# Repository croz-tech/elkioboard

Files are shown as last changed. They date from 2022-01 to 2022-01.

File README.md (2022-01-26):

# elkioboard
I/O board for Acorn Electron (with user port cart) or BBC Micro range

Compatible with many 8-bit robot or control projects. Inputs are for switches (switches from input to +5V), Outputs drive relays.
|Bit  |Alloc |Details |
|-----|---|---|
|PB0  | Out only | DPDT relay (can be configured to reverse a motor drive)|
|PB1  | Out only | SPDT relay|
|PB2  | In/Out | Input switched to +5V  / SPDT relay (selectable by JP1)|
|PB3  | In/Out | Input switched to +5V  / SPDT relay (selectable by JP2)|
|PB4  | In/Out | Input switched to +5V  / SPDT relay (selectable by JP3)|
|PB5  | In/Out | Input switched to +5V  / SPDT relay (selectable by JP4)|
|PB6  | In only  | Input switched to +5V|
|PB7  | In only  | Input switched to +5V|

Includes a local 5V supply (since the total load with all specified relays energized may be too much for the user port itself, and generates an adjustable MOTPWR supply for motors, solenoids etc that the system is driving.  MOTPWR can be monitored with a small DVM module (3-pin header provided).  There is also a header and power/ground for CB1/CB2 from the user port (not used on this board).

## Notes
- Remember the base address for the 6522 PIA is &FE6x BBC Micro and &FCBx Electron with user port cartiridge in a Plus 1
- RV1 needs to be 5x5mm pin spacing, specified as 500R but 1K also works just fine and gives an adjustable motor supply of 2.5~9V approx.

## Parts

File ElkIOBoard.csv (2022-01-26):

Reference | Quantity | Value | Footprint | Datasheet
C1 | 1 | 10uF 16V | Capacitor_THT:CP_Radial_D5.0mm_P2.00mm | ~
C2 | 1 | 470uF, 25V | Capacitor_THT:CP_Radial_D10.0mm_P5.00mm | ~
C3 | 1 | 100uF, 25V | Capacitor_THT:CP_Radial_D6.3mm_P2.50mm | ~
C4 | 1 | 100nF | Capacitor_THT:C_Rect_L7.0mm_W2.5mm_P5.00mm | ~
F1 | 1 | Polyfuse (1.5A rec) | Capacitor_THT:C_Disc_D10.5mm_W5.0mm_P5.00mm | ~
J1 | 1 | POWER IN | TerminalBlock_Philmore:TerminalBlock_Philmore_TB132_1x02_P5.00mm_Horizontal | ~
J10 | 1 | In bit 6 | TerminalBlock_Philmore:TerminalBlock_Philmore_TB132_1x02_P5.00mm_Horizontal | ~
J11 | 1 | In bit 7 | TerminalBlock_Philmore:TerminalBlock_Philmore_TB132_1x02_P5.00mm_Horizontal | ~
J12 J13 J14 J15 J16 J17 J18 | 7 | NO.COM.NC | TerminalBlock_Philmore:TerminalBlock_Philmore_TB133_1x03_P5.00mm_Horizontal | ~
J2 | 1 | POWER OUT | TerminalBlock_Philmore:TerminalBlock_Philmore_TB132_1x02_P5.00mm_Horizontal | ~
J3 | 1 | USER PORT | ElkIOBoard:20W_IDC_TERM | ~
J4 | 1 | EXP CONN | Connector_PinHeader_2.54mm:PinHeader_1x05_P2.54mm_Vertical | ~
J5 | 1 | DVM | Connector_PinHeader_2.54mm:PinHeader_1x03_P2.54mm_Vertical | ~
J6 | 1 | In bit 2 | TerminalBlock_Philmore:TerminalBlock_Philmore_TB132_1x02_P5.00mm_Horizontal | ~
J7 | 1 | In bit 3 | TerminalBlock_Philmore:TerminalBlock_Philmore_TB132_1x02_P5.00mm_Horizontal | ~
J8 | 1 | In bit 4 | TerminalBlock_Philmore:TerminalBlock_Philmore_TB132_1x02_P5.00mm_Horizontal | ~
J9 | 1 | In bit 5 | TerminalBlock_Philmore:TerminalBlock_Philmore_TB132_1x02_P5.00mm_Horizontal | ~
JP1 JP2 JP3 JP4 | 4 | Jumper_3_Bridged12 | Connector_PinHeader_2.54mm:PinHeader_1x03_P2.54mm_Vertical | ~
K1 K2 K3 K4 K5 | 5 | SRD-05VDC-SL-C | Relay_THT:Relay_SPDT_SANYOU_SRD_Series_Form_C | http://www.sanyourelay.ca/public/products/pdf/SRD.pdf
K6 | 1 | FINDER DPDT5V | Relay_THT:Relay_DPDT_Finder_30.22 | http://gfinder.findernet.com/assets/Series/354/S30EN.pdf
LED1 | 1 | STATUS | Display:HDSP-4830 | https://docs.broadcom.com/docs/AV02-1798EN
R1 R2 R3 R4 R5 R6 | 6 | 220R | Resistor_THT:R_Axial_DIN0207_L6.3mm_D2.5mm_P10.16mm_Horizontal | ~
R7 R8 R9 R10 R11 R12 | 6 | 10K | Resistor_THT:R_Axial_DIN0207_L6.3mm_D2.5mm_P10.16mm_Horizontal | ~
R13 R14 R15 R16 R17 R18 | 6 | 2K2 | Resistor_THT:R_Axial_DIN0207_L6.3mm_D2.5mm_P10.16mm_Horizontal | ~
R19 | 1 | 130R | Resistor_THT:R_Axial_DIN0207_L6.3mm_D2.5mm_P10.16mm_Horizontal | ~
RN1 RN2 | 2 | 150R | Resistor_THT:R_Array_SIP6 | http://www.vishay.com/docs/31509/csc.pdf
RV1 | 1 | 500R | Potentiometer_THT:Potentiometer_Piher_PT-10-V05_Vertical | ~
U1 | 1 | ULN2003A | Package_DIP:DIP-16_W7.62mm_LongPads | http://www.ti.com/lit/ds/symlink/uln2003a.pdf
U2 | 1 | LM7805 | Package_TO_SOT_THT:TO-220-3_Horizontal_TabDown | http://www.fairchildsemi.com/ds/LM/LM7805.pdf
U3 | 1 | LM317T | Package_TO_SOT_THT:TO-220-3_Horizontal_TabDown | http://www.ti.com/lit/ds/symlink/lm317.pdf
U4 | 1 | 74LS240 | Package_DIP:DIP-20_W7.62mm_LongPads | http://www.ti.com/lit/gpn/sn74LS240

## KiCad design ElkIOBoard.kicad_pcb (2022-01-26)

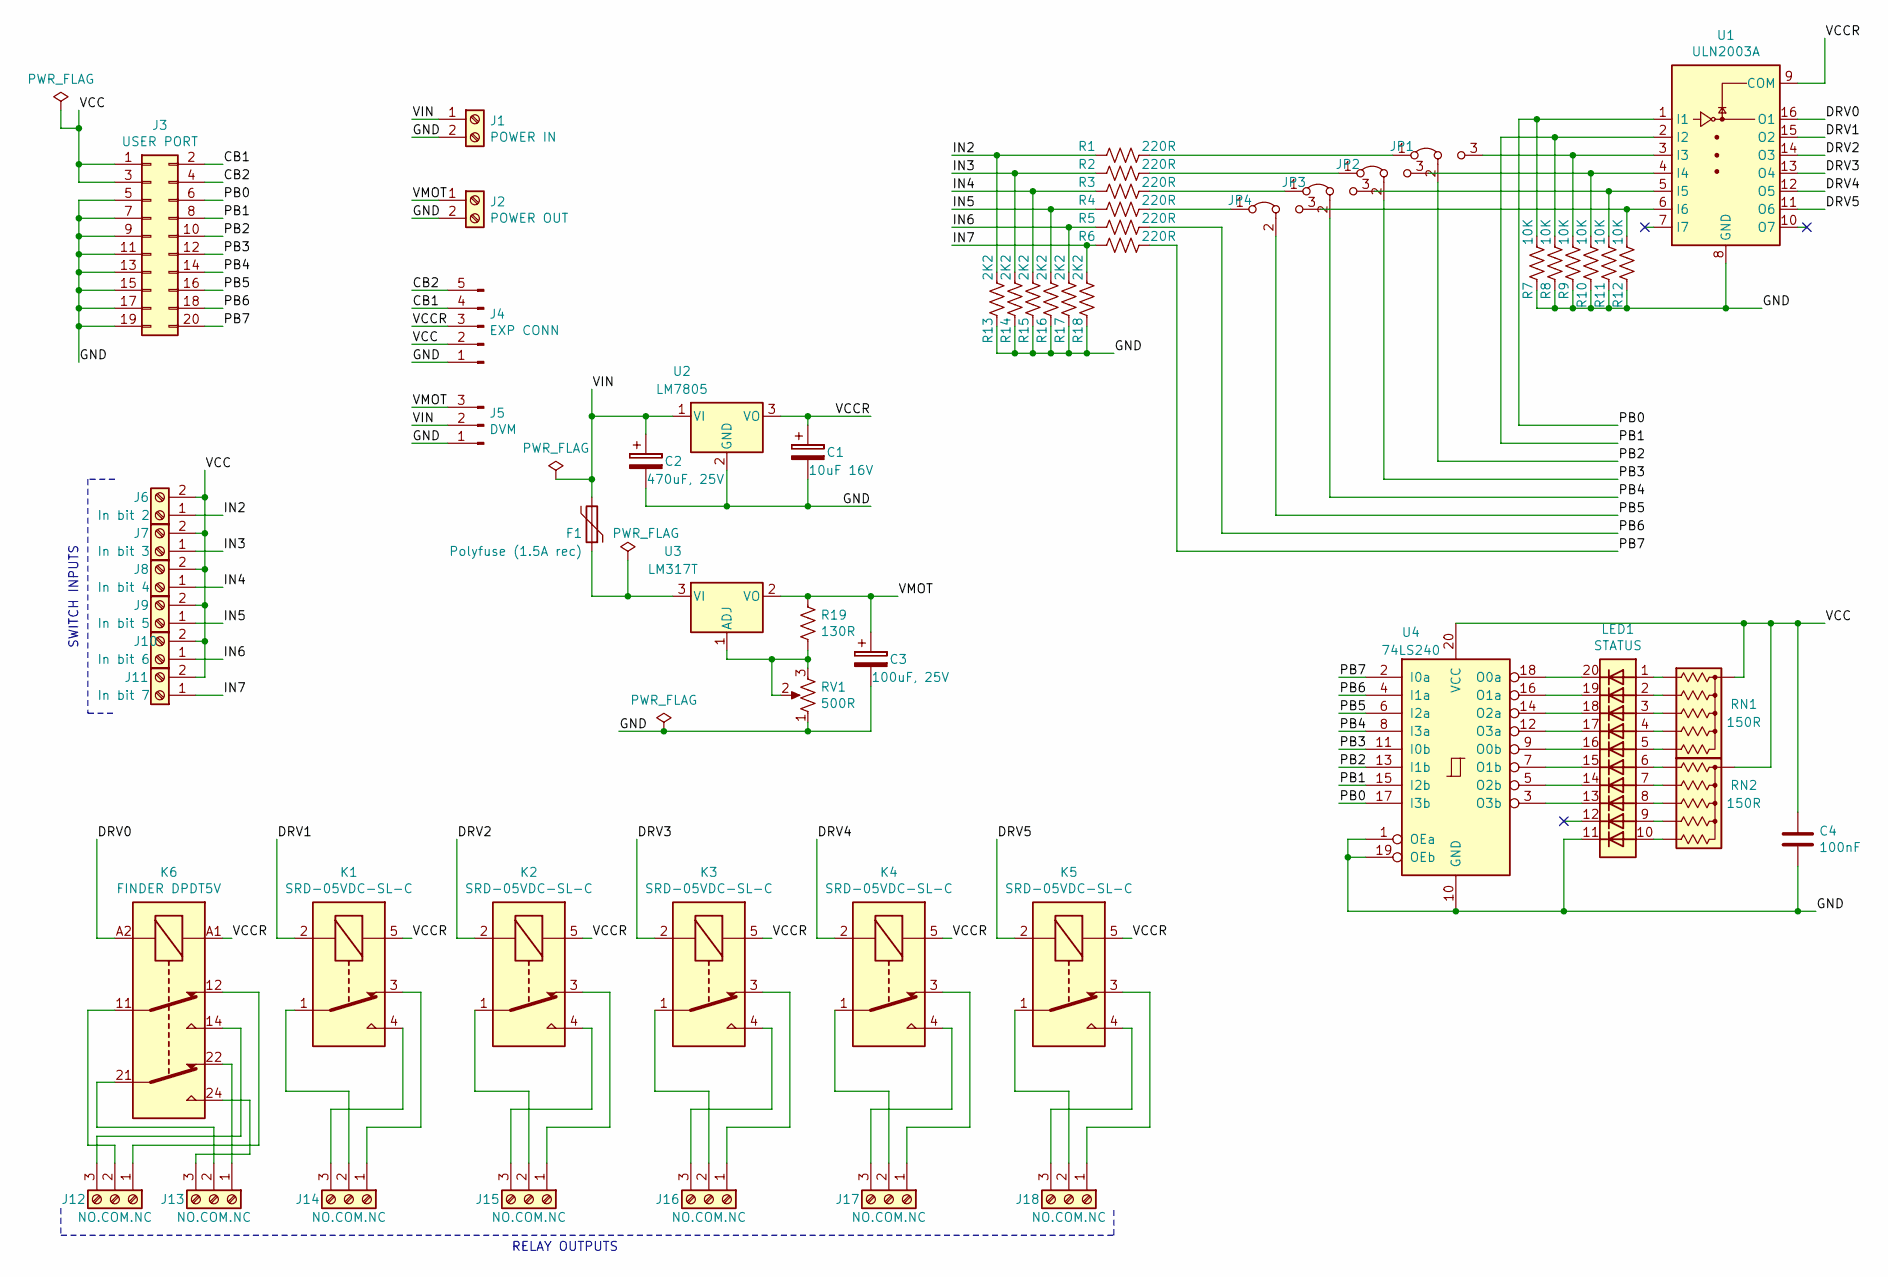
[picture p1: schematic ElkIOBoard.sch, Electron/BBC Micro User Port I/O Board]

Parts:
C1: 10uF 16V; CP_Radial_D5.0mm_P2.00mm
C2: 470uF, 25V; CP_Radial_D10.0mm_P5.00mm
C3: 100uF, 25V; CP_Radial_D6.3mm_P2.50mm
C4: 100nF; C_Rect_L7.0mm_W2.5mm_P5.00mm
F1: Polyfuse (1.5A rec); C_Disc_D10.5mm_W5.0mm_P5.00mm
J1: POWER IN; TerminalBlock_Philmore_TB132_1x02_P5.00mm_Horizontal
J2: POWER OUT; TerminalBlock_Philmore_TB132_1x02_P5.00mm_Horizontal
J3: USER PORT; 20W_IDC_TERM
J4: EXP CONN; PinHeader_1x05_P2.54mm_Vertical
J5: DVM; PinHeader_1x03_P2.54mm_Vertical
J6: In bit 2; TerminalBlock_Philmore_TB132_1x02_P5.00mm_Horizontal
J7: In bit 3; TerminalBlock_Philmore_TB132_1x02_P5.00mm_Horizontal
J8: In bit 4; TerminalBlock_Philmore_TB132_1x02_P5.00mm_Horizontal
J9: In bit 5; TerminalBlock_Philmore_TB132_1x02_P5.00mm_Horizontal
J10: In bit 6; TerminalBlock_Philmore_TB132_1x02_P5.00mm_Horizontal
J11: In bit 7; TerminalBlock_Philmore_TB132_1x02_P5.00mm_Horizontal
J12, J13, J14, J15, J16, J17, J18: NO.COM.NC; TerminalBlock_Philmore_TB133_1x03_P5.00mm_Horizontal
JP1, JP2, JP3, JP4: Jumper_3_Bridged12; PinHeader_1x03_P2.54mm_Vertical
K1, K2, K3, K4, K5: SRD-05VDC-SL-C; Relay_SPDT_SANYOU_SRD_Series_Form_C
K6: FINDER DPDT5V; Relay_DPDT_Finder_30.22
LED1: STATUS; HDSP-4830
R1, R2, R3, R4, R5, R6: 220R; R_Axial_DIN0207_L6.3mm_D2.5mm_P10.16mm_Horizontal
R7, R8, R9, R10, R11, R12: 10K; R_Axial_DIN0207_L6.3mm_D2.5mm_P10.16mm_Horizontal
R13, R14, R15, R16, R17, R18: 2K2; R_Axial_DIN0207_L6.3mm_D2.5mm_P10.16mm_Horizontal
R19: 130R; R_Axial_DIN0207_L6.3mm_D2.5mm_P10.16mm_Horizontal
RN1, RN2: 150R; R_Array_SIP6
RV1: 500R; Potentiometer_Piher_PT-10-V05_Vertical
U1: ULN2003A; DIP-16_W7.62mm_LongPads
U2: LM7805; TO-220-3_Horizontal_TabDown
U3: LM317T; TO-220-3_Horizontal_TabDown
U4: 74LS240; DIP-20_W7.62mm_LongPads

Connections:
/CB1: J3.2, J4.4
/CB2: J3.4, J4.5
/DRV0: K6.A2, U1.16 (O1)
/DRV1: K1.2, U1.15 (O2)
/DRV2: K2.2, U1.14 (O3)
/DRV3: K3.2, U1.13 (O4)
/DRV4: K4.2, U1.12 (O5)
/DRV5: K5.2, U1.11 (O6)
/GND: C1.2, C2.2, C3.2, C4.2, J1.2, J2.2, J3.5, J3.7, J3.9, J3.11, J3.13, J3.15, J3.17, J3.19, J4.1, J5.1, LED1.11 (K), R7.1, R8.1, R9.1, R10.1, R11.1, R12.1, R13.2, R14.2, R15.2, R16.2, R17.2, R18.2, RV1.1, U1.8 (GND), U2.2 (GND), U4.1 (OEa), U4.10 (GND), U4.19 (OEb)
/IN2: J6.1, R1.2, R13.1
/IN3: J7.1, R2.2, R14.1
/IN4: J8.1, R3.2, R15.1
/IN5: J9.1, R4.2, R16.1
/IN6: J10.1, R5.2, R17.1
/IN7: J11.1, R6.2, R18.1
/PB0: J3.6, R7.2, U1.1 (I1), U4.17 (I3b)
/PB1: J3.8, R8.2, U1.2 (I2), U4.15 (I2b)
/PB2: J3.10, JP1.2 (C), U4.13 (I1b)
/PB3: J3.12, JP2.2 (C), U4.11 (I0b)
/PB4: J3.14, JP3.2 (C), U4.8 (I3a)
/PB5: J3.16, JP4.2 (C), U4.6 (I2a)
/PB6: J3.18, R5.1, U4.4 (I1a)
/PB7: J3.20, R6.1, U4.2 (I0a)
/VCC: C4.1, J3.1, J3.3, J4.2, J6.2, J7.2, J8.2, J9.2, J10.2, J11.2, RN1.1 (common), RN2.1 (common), U4.20 (VCC)
/VCCR: C1.1, J4.3, K1.5, K2.5, K3.5, K4.5, K5.5, K6.A1, U1.9 (COM), U2.3 (VO)
/VIN: C2.1, F1.2, J1.1, J5.2, U2.1 (VI)
/VMOT: C3.1, J2.1, J5.3, R19.1, U3.2 (VO)
unnamed: F1.1, U3.3 (VI)
unnamed: J12.1, K6.12
unnamed: J12.2, K6.11
unnamed: J12.3, K6.14
unnamed: J13.1, K6.22
unnamed: J13.2, K6.21
unnamed: J13.3, K6.24
unnamed: J14.1, K1.3
unnamed: J14.2, K1.1
unnamed: J14.3, K1.4
unnamed: J15.1, K2.3
unnamed: J15.2, K2.1
unnamed: J15.3, K2.4
unnamed: J16.1, K3.3
unnamed: J16.2, K3.1
unnamed: J16.3, K3.4
unnamed: J17.1, K4.3
unnamed: J17.2, K4.1
unnamed: J17.3, K4.4
unnamed: J18.1, K5.3
unnamed: J18.2, K5.1
unnamed: J18.3, K5.4
unnamed: JP1.1 (A), R1.1
unnamed: JP1.3 (B), R9.2, U1.3 (I3)
unnamed: JP2.1 (A), R2.1
unnamed: JP2.3 (B), R10.2, U1.4 (I4)
unnamed: JP3.1 (A), R3.1
unnamed: JP3.3 (B), R11.2, U1.5 (I5)
unnamed: JP4.1 (A), R4.1
unnamed: JP4.3 (B), R12.2, U1.6 (I6)
unnamed: LED1.1 (A), RN1.2 (R1)
unnamed: LED1.2 (A), RN1.3 (R2)
unnamed: LED1.3 (A), RN1.4 (R3)
unnamed: LED1.4 (A), RN1.5 (R4)
unnamed: LED1.5 (A), RN1.6 (R5)
unnamed: LED1.6 (A), RN2.2 (R1)
unnamed: LED1.7 (A), RN2.3 (R2)
unnamed: LED1.8 (A), RN2.4 (R3)
unnamed: LED1.9 (A), RN2.5 (R4)
unnamed: LED1.10 (A), RN2.6 (R5)
unnamed: LED1.13 (K), U4.3 (O3b)
unnamed: LED1.14 (K), U4.5 (O2b)
unnamed: LED1.15 (K), U4.7 (O1b)
unnamed: LED1.16 (K), U4.9 (O0b)
unnamed: LED1.17 (K), U4.12 (O3a)
unnamed: LED1.18 (K), U4.14 (O2a)
unnamed: LED1.19 (K), U4.16 (O1a)
unnamed: LED1.20 (K), U4.18 (O0a)
unnamed: R19.2, RV1.2, RV1.3, U3.1 (ADJ)

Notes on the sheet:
RELAY OUTPUTS
SWITCH INPUTS

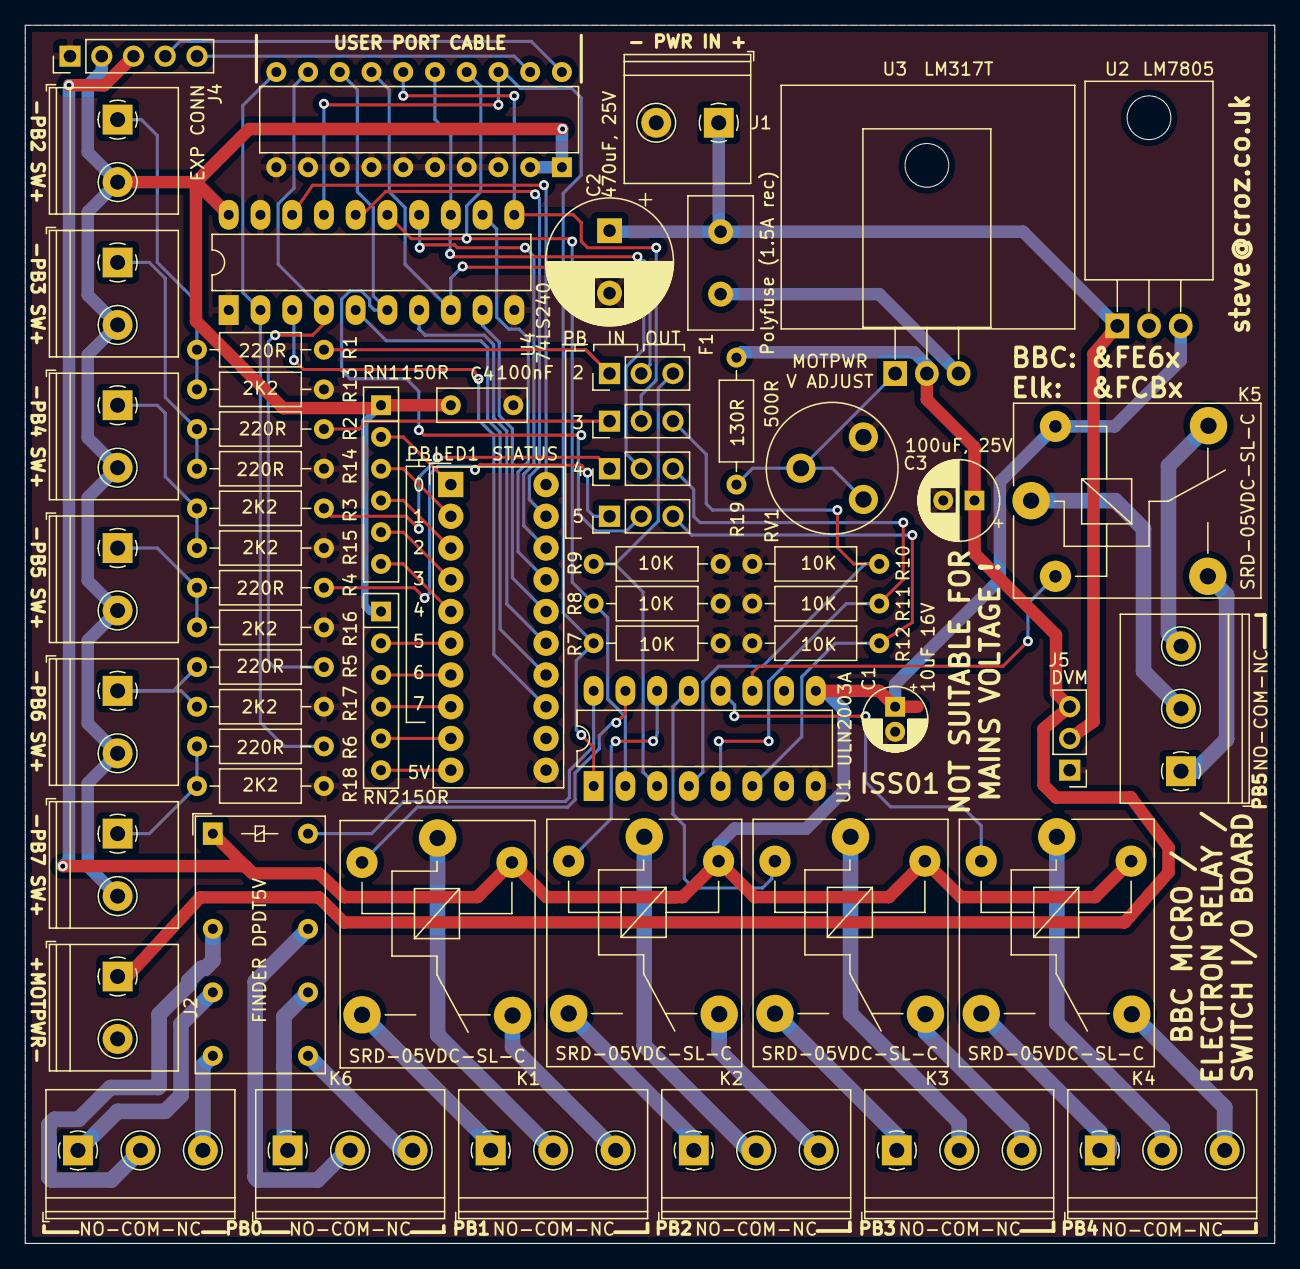
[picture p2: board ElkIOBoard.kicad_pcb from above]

Board: 2 copper layers, 100.0 x 97.5 mm, 60 parts (0 on the bottom side), 76 nets.
